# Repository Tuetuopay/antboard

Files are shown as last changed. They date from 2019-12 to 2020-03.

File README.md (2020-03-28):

# Antboard

An STM32 dev board with 1.27mm headers for GPIOs that got a bit over the top.
Yeah this is a kitchen sink board now...

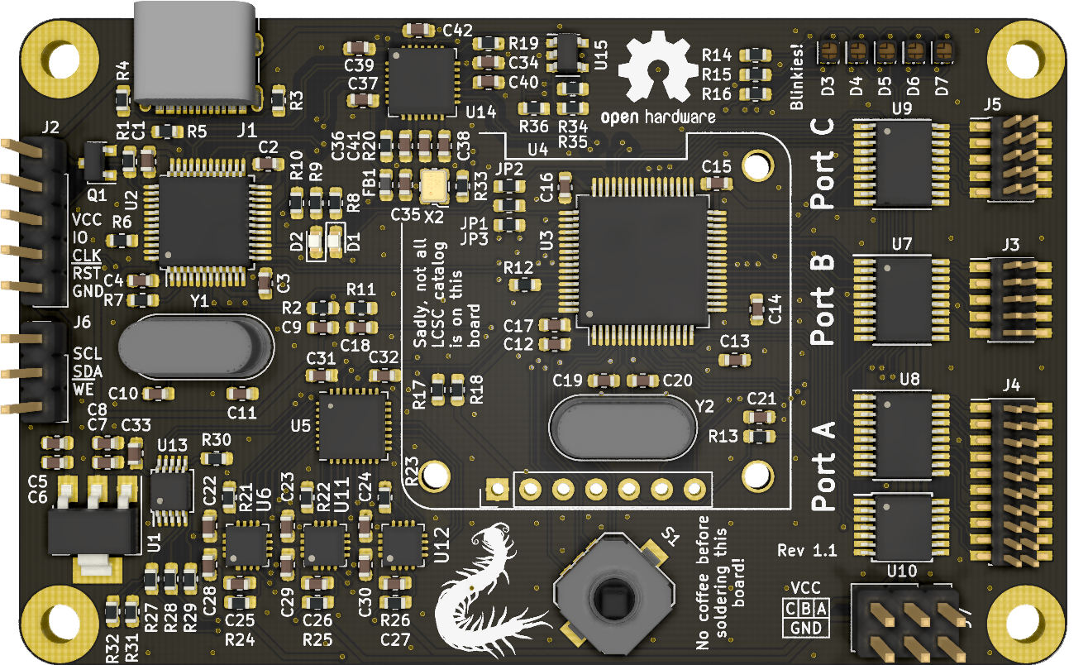
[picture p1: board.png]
antboard


## Features

* STM32F405 microcontroller
* 3 independant IO banks routed to 1.27mm headers (1x 10 IO, 2x 5 IO)
  - bidirectional level shifter
  - shifter supply voltage controllable through software
* accepts IDC ribbon cables
* integrated ST-LINK/V2 probe (compatible with BlackMagic firmware)
* integrated USB hub for both JTAG and user USB
* integrated ADC to control set bank voltages
* OLED screen
* joystick
* 5 RGB LEDs, just because blinkies

All components can be sourced on the usual distributors, and for cheap on LCSC.

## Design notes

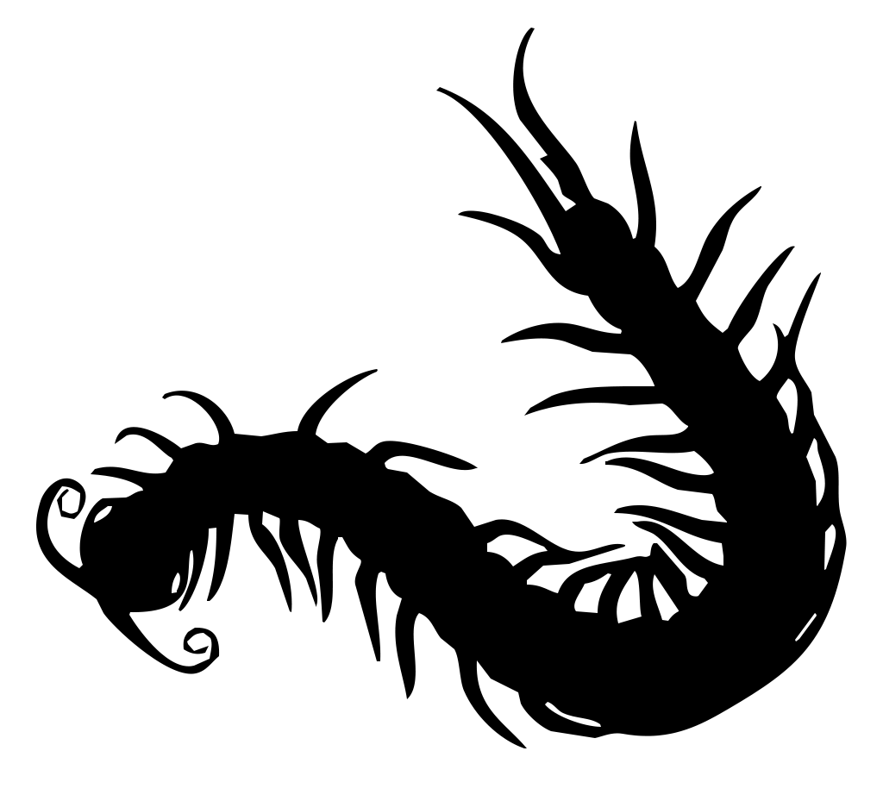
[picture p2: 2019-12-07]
ant.png

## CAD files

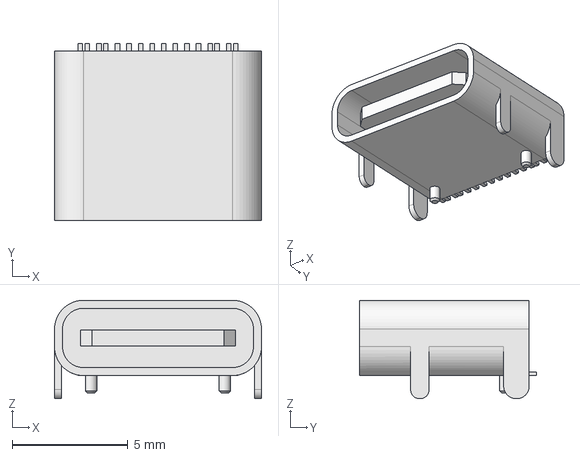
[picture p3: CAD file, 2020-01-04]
3d/USB_C_Receptacle_Palconn_UTC16-G-fusion.step
8.94 x 7.63 x 4.25 mm

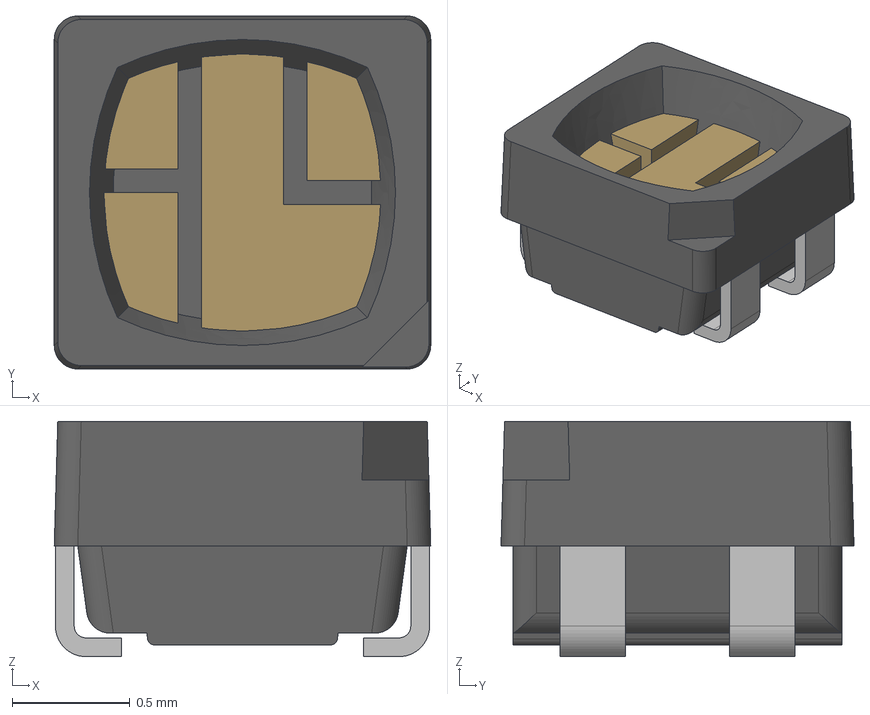
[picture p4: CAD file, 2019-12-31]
3d/MHPA1515RGBDT.step
1.60 x 1.50 x 1.00 mm
Leads
Die

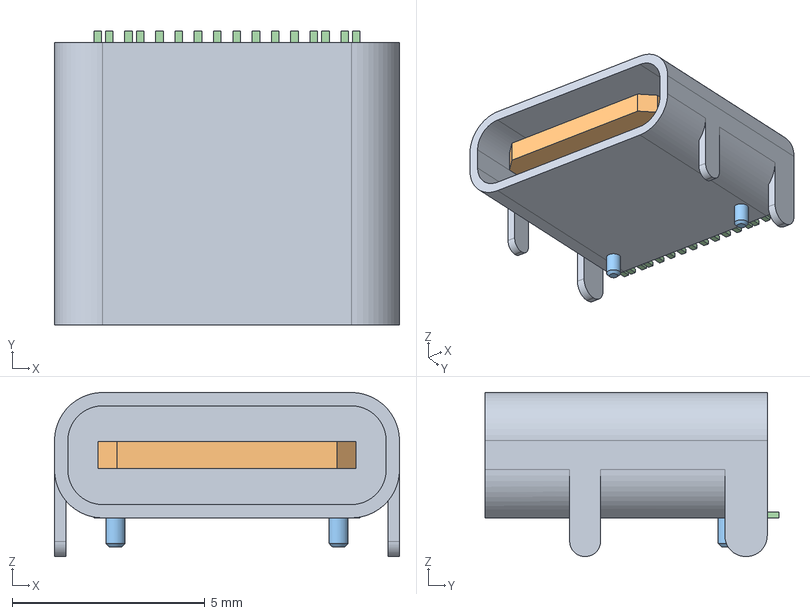
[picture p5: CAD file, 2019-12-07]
3d/USB_C_Receptacle_Palconn_UTC16-G.step
8.94 x 7.63 x 4.25 mm

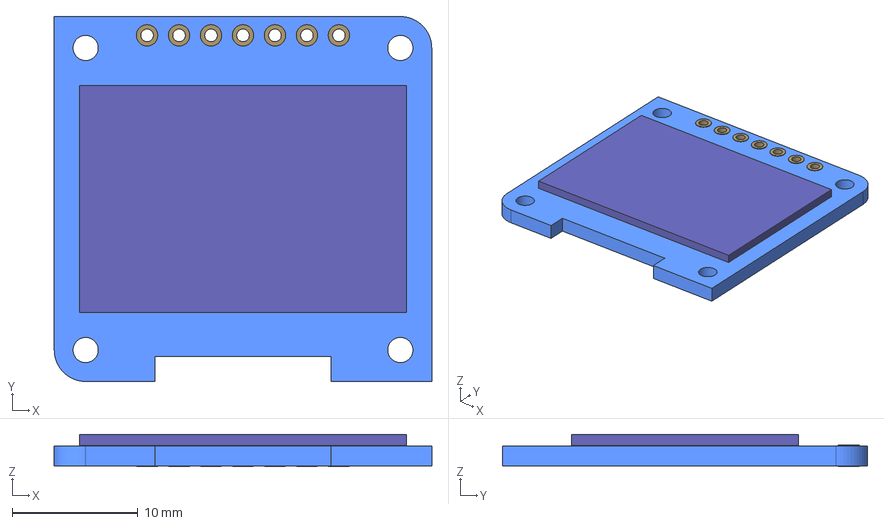
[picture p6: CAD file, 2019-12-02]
3d/OLED_0.96_SSD1306.step
30.0 x 29.0 x 2.55 mm
PCB
Contacts
Screen

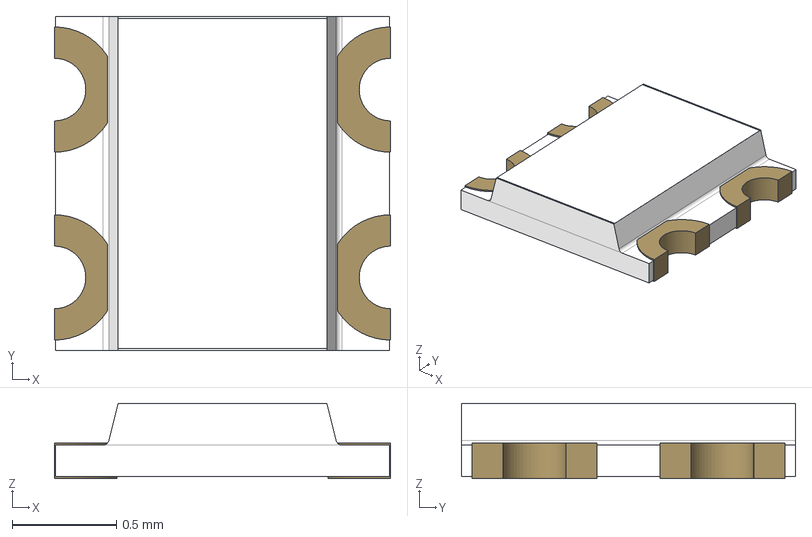
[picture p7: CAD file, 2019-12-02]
3d/19-237_R6GHBHC-A01_2T.step
1.61 x 1.60 x 0.36 mm
Plastic
Contacts

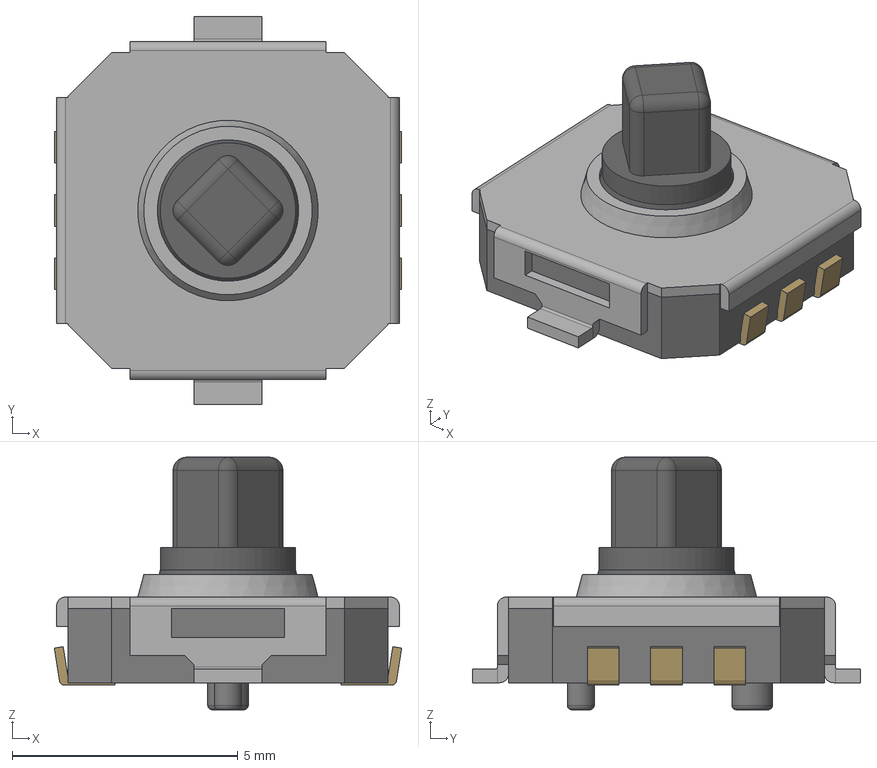
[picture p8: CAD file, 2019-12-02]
3d/K1-5202UA-03.step
7.70 x 8.60 x 5.60 mm
Shield
Stick
Contacts
Base

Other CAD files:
3d/19-237_R6GHBHC-A01_2T.FCStd
3d/K1-5202UA-03.FCStd
3d/MHPA1515RGBDT.FCStd
3d/OLED_0.96_SSD1306.FCStd

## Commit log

2019-11-27 STM32 schematic mostly done
    [antboard.sch, st_link.sch]
2019-11-28 Better sch segmentation and add TCA6424A symbol
    [antboard.sch, io.sch, io_power.sch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]
2019-11-29 Done adding the kitchen sink
    [antboard.sch, io.sch, io_power.sch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]
2019-11-29 Annotate schematic
    [io_power.sch, stm32.sch]
2019-12-02 Schematic mostly done, place begun
    [19-237_R6GHBHC-A01_2T.FCStd, 19-237_R6GHBHC-A01_2T.step, K1-5202UA-03.FCStd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]
2019-12-03 Misc sch fixes and psu p&r done
    [antboard.kicad_pcb, io_power.sch]
2019-12-03 pcb: Place some caps
    [antboard.kicad_pcb]
2019-12-07 Routing should be done
    [USB_C_Receptacle_Palconn_UTC16-G.step, antboard.kicad_pcb, io.sch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]
2019-12-07 Stitch ground and add ants to silkscreen
    [antboard.kicad_pcb]
2019-12-08 Misc silk fixes and add power header
    [antboard.kicad_pcb, io_power.sch]
2019-12-31 sch, pcb: Add ADC to read set IO voltages
    [antboard.kicad_pcb, antboard.sch, io_power.sch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]
2019-12-31 sch, pcb: Change RGB LEDs to MHPA1515
    [MHPA1515RGBDT.FCStd, MHPA1515RGBDT.step, antboard.kicad_pcb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]
2019-12-31 sch, pcb: Add a 5th RGB LED
    [antboard.kicad_pcb, stm32.sch]
2019-12-31 ci: Use image for 2-layer boards
2019-12-31 pcb: Add rev to silkscreen
    [antboard.kicad_pcb]
2020-01-04 pcb: Fix solder mask minimum width
    [antboard.kicad_pcb]
2020-01-04 3d: Add missing unibody USB-C connector
    [USB_C_Receptacle_Palconn_UTC16-G-fusion.step]
2020-01-04 sch, pcb: Add USB hub to have a single USB port
    [antboard.kicad_pcb, antboard.sch, hub.sch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]
2020-01-04 Fix USB hub GND and add nag silk messages
    [antboard.kicad_pcb]
2020-01-04 Add solder bridges in line with the integrated JTAG
    Just in case it does not works
    [antboard.kicad_pcb, stm32.sch]
2020-01-05 sch, pcb: Add I²C EEPROM for USB hub
    [antboard.kicad_pcb, hub.sch]
2020-01-05 sch, pcb: Add header to access EEPROM I²C bus
    [antboard.kicad_pcb, hub.sch]
2020-01-05 pcb: Fix C33 silk placement
    [antboard.kicad_pcb]
2020-01-06 sch: Fix LED resistors
    [stm32.sch]
2020-01-15 sch, pcb: Remove CLKEN and EEPROM SCL pullup
    [antboard.kicad_pcb, hub.sch]
2020-01-15 Rev 1.2
    [antboard.kicad_pcb]
2020-03-28 sch, pcb: Fix hub startup and use smaller crystals
    [antboard.kicad_pcb, hub.sch, st_link.sch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]
2020-03-28 sch: Remove cache from libs to make kicad happy
    [antboard.sch, hub.sch, io.sch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]
2020-03-28 sch, pcb: Replace STM32F205 with STM32F405
    A Rust HAL is available for the F4 series and not for the F2 series...
    [antboard.kicad_pcb, stm32.sch]
2020-03-28 sch: List LCSC P/N for each component
    [antboard.kicad_pcb, hub.sch, io.sch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]
2020-03-29 fp, pcb: Fix OLED screen pinout
    [antboard.kicad_pcb]
2020-03-29 *: Add VCAP decoupling caps
    CPU had strange behaviours without it (IRQs fired only once, random
    SEGFAULTs, ...)
    [antboard.kicad_pcb, stm32.sch]
2020-03-29 sch, pcb: Repurpose OLED CS as OLED RST
    Since the OLED is the only device off the SPI bus, it makes no sense to
    have a CS pin
    [antboard.kicad_pcb, stm32.sch]
2020-03-30 sch, pcb: Connect TCA epad to GND
    [antboard.kicad_pcb, io_power.sch]
2020-03-30 fp: Fix K1-5202 footprint
    Pins were flipped along the Y axis...
2020-03-30 sch, pcb: Rewire joystick following pinout fix
    [antboard.kicad_pcb, stm32.sch]
2020-03-30 pcb: Change OSHW logo from Silk to Mask cutout
    [antboard.kicad_pcb]
2020-03-31 Rev 1.3
    [antboard.kicad_pcb]
2020-03-31 sch: Fix quartz load capacitors values
    They were 100n, thanks copy/paste..
    [st_link.sch, stm32.sch]
